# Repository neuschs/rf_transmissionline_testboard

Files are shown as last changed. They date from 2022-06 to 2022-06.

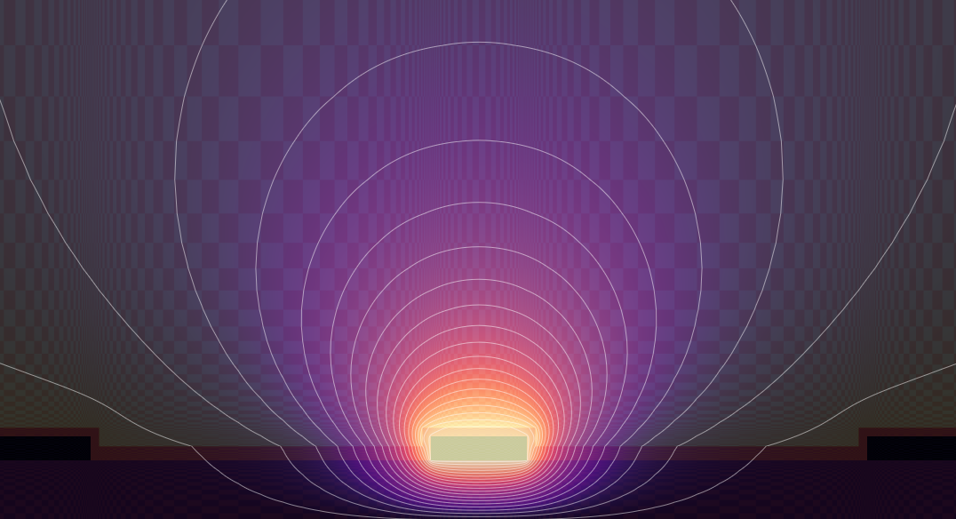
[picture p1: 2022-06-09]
calculations/coplanar_waveguide_single_e_field.png

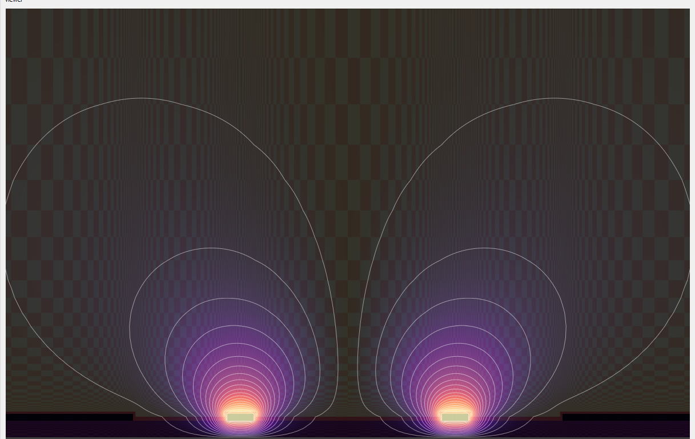
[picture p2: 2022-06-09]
calculations/coplanar_waveguide_differential_e_field.png

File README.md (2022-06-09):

# Transmission Line Testboard 
A simple PCB designed according to JLC23313 layer stackup 

There are many different impedance controlled transmission lines, with the most common Zo = 50 Ohm / Zdiff = 100 Ohm

- Coplanar Waveguide (Single / Differential)

- Microstrip (Single / Differential)

- Stripline (Single / Differential):

  A impedance controlled Via and a set of differential vias gets the stripline up to a coplanar waveguide to the sma connectors
  For a future version vertical SMA mounts would be better to avoid vias where the goal was to proof impedance control calculations.
 
- 90° track (as Coplanar Waveguide)

  I put this track on the pcb to measure the effects of 90° bends on transmission lines.

- 50% top 50% bottom track connected by 50 ohm via:
 to verify impedance of via if the coplanar waveguide calculations are all correct.

# Parameters @ production:

Base Material: FR-4\
Layers: 4\
Dimension: 100 mm* 100 mm\
PCB Qty: 5\
Product Type: Industrial/Consumer electronics\
Different Design: 1\
Delivery Fomat: Single PCB\
PCB Thickness: 1.6\
Impedance: yes JLC2313\
PCB Color: Green\
Silkscreen: White\
Surface Finish: HASL(with lead)\
Deburring/Edge rounding: No\
Outer Copper Weight: 1\
Inner Copper Weight: 0.5\
Gold Fingers: No\
Flying Probe Test: Fully Test\
Castellated Holes: no\
Remove Order Number: Yes\
Min hole size/diameter:0.2/0.45mm\
4-Wire Kelvin Test:No\
Material Type:FR4-Standard Tg 130-140C\
Paper between PCBs:No\
Appearance Quality:IPC Class 2 Standard\
Confirm Production file:Yes

# Credits
I mostly calculated the values with https://www.maartenbaert.be/alterpcb/tlinesim/ which has quite accurate interpretation of all different parts of the pcb.
After comparison, this tool was nearly exactly the same to the manufacturer (JLCPCB) regarding a 50 Ohm transmission line with JLC2313 stackup.

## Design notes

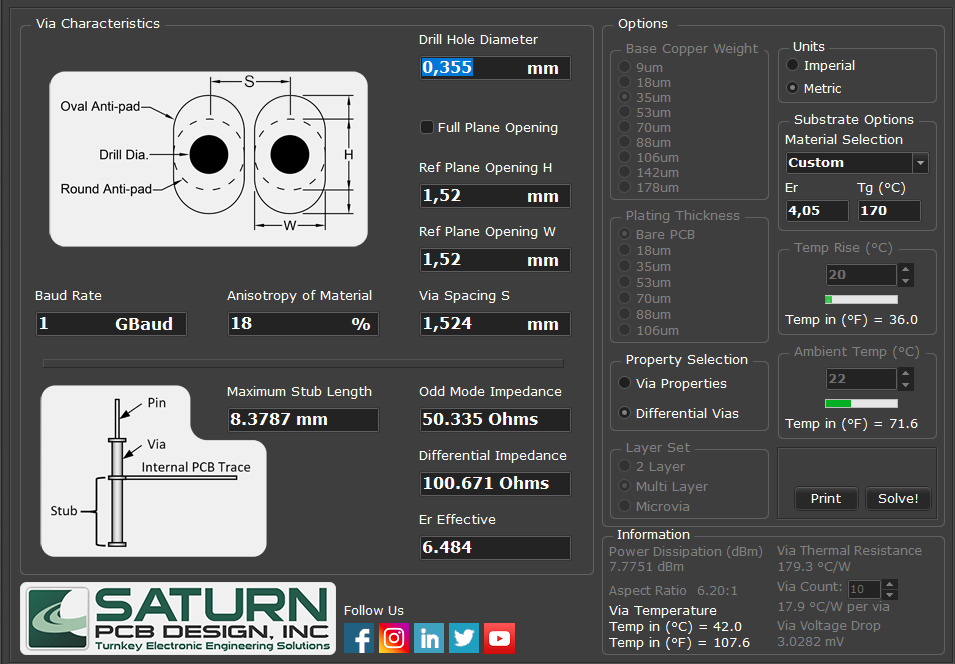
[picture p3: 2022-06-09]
calculations/differential via.png

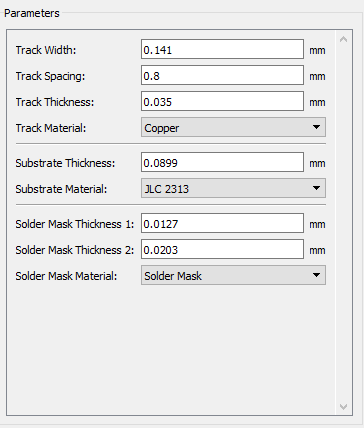
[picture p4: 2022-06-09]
calculations/microstrip_differential_parameters.png

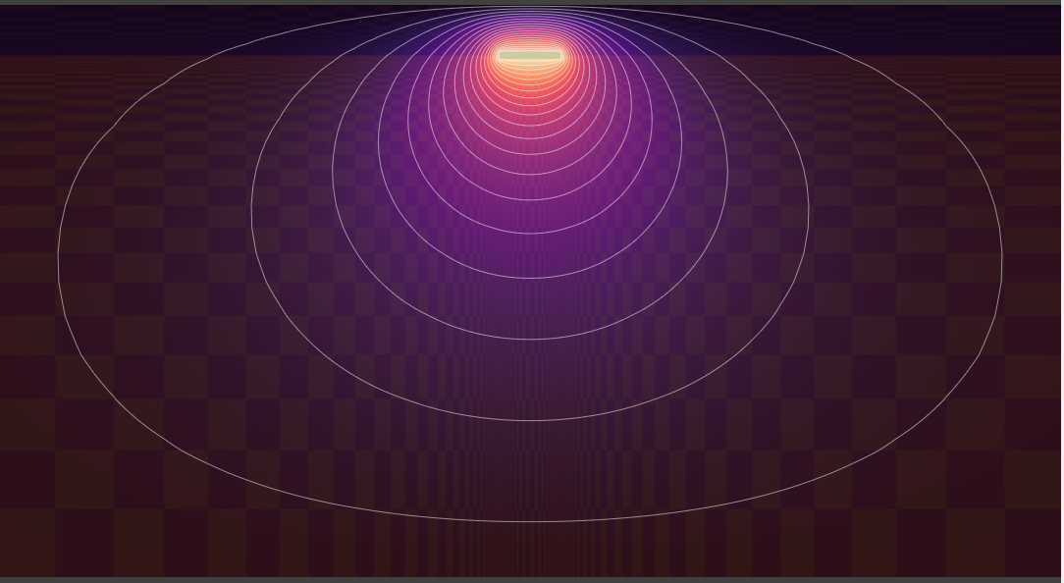
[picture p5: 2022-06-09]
calculations/stripline_single_e_field_layer_2.png

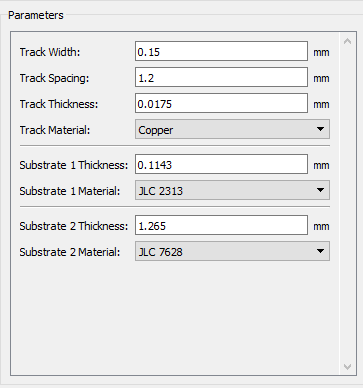
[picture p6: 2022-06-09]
calculations/stripline_differential_parameters.png

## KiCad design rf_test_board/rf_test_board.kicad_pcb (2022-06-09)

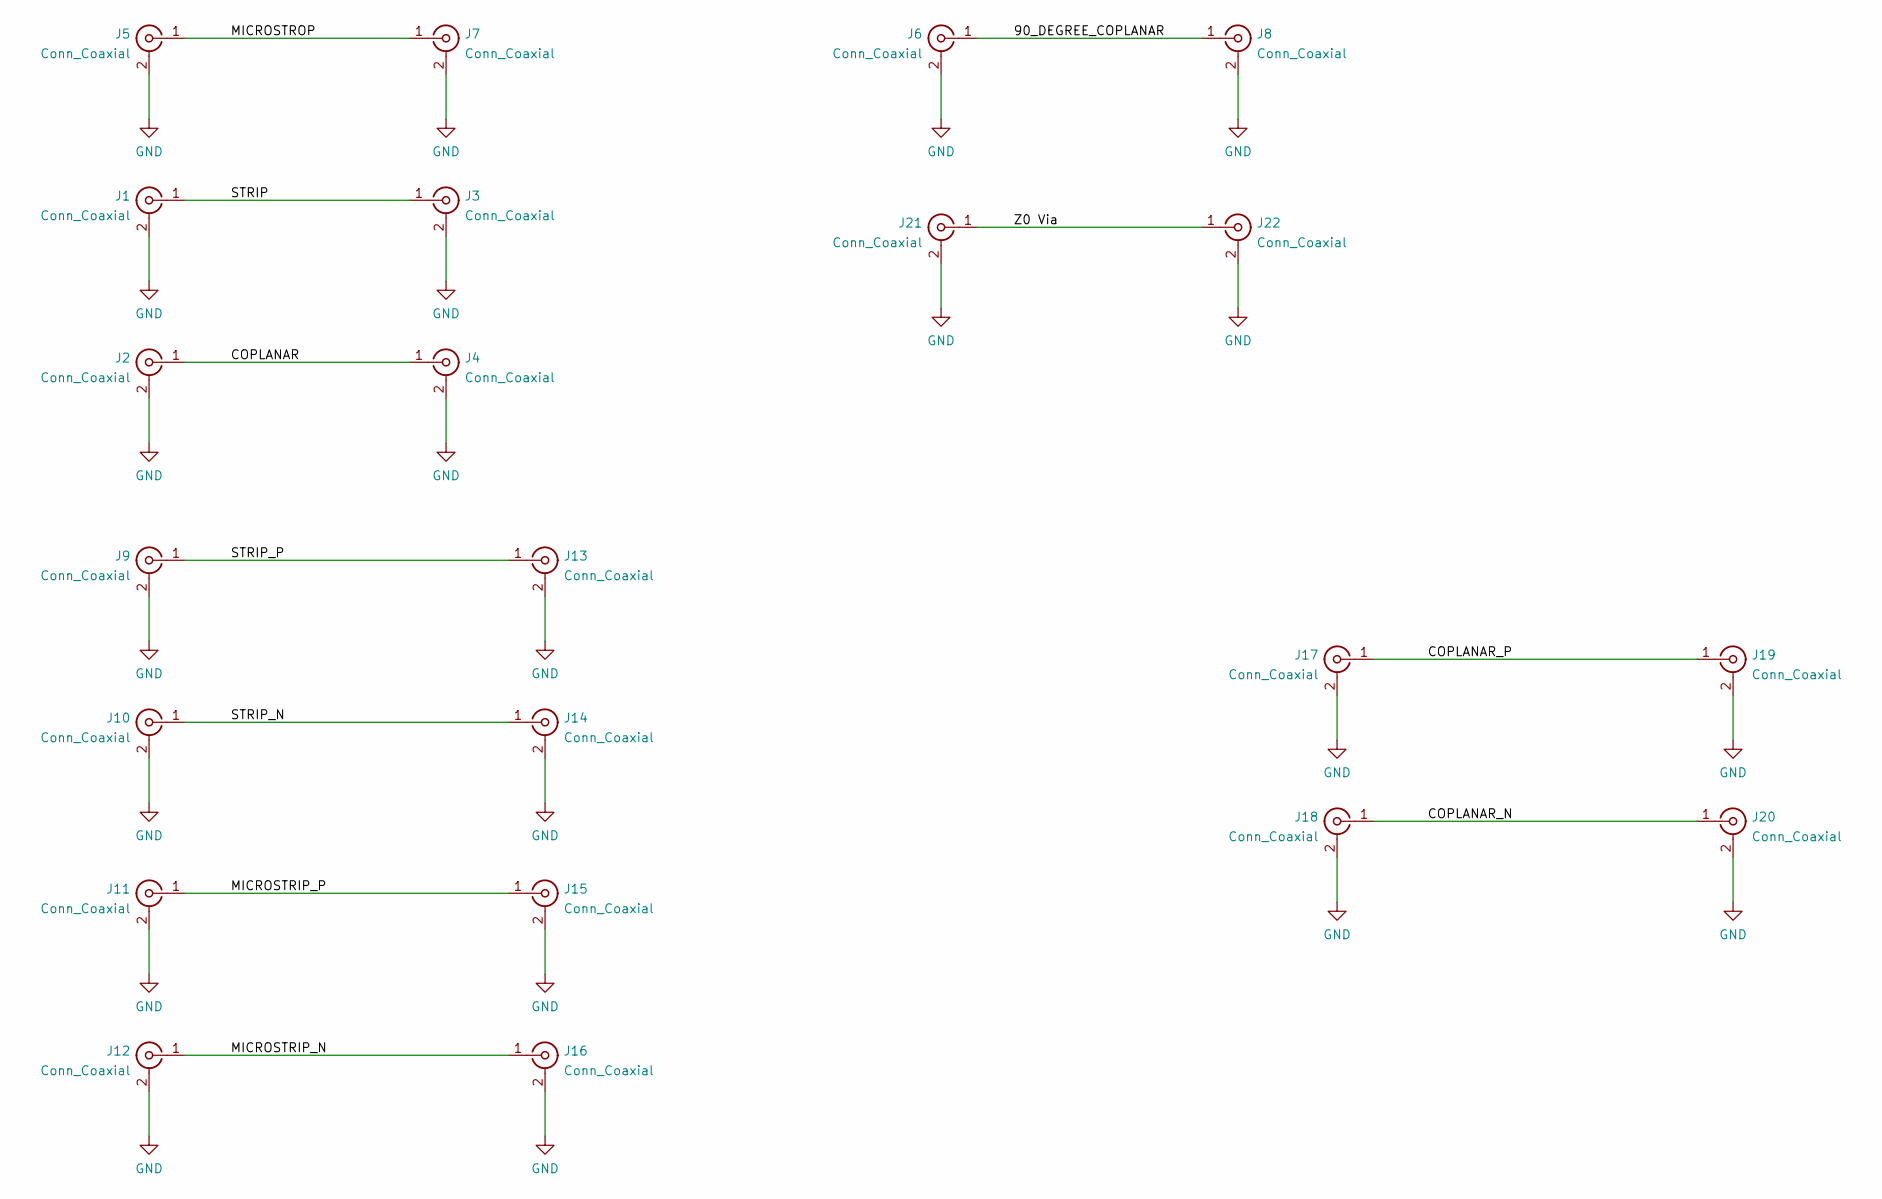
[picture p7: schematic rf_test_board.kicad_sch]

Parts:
J1, J2, J3, J4, J5, J6, J7, J8, J9, J10, J11, J12, J13, J14, J15, J16, J17, J18, J19, J20, J21, J22: Conn_Coaxial; SMA_Molex_73251-1153_EdgeMount_Horizontal

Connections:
/90_DEGREE_COPLANAR: J6.1 (In), J8.1 (In)
/COPLANAR: J2.1 (In), J4.1 (In)
/COPLANAR_N: J18.1 (In), J20.1 (In)
/COPLANAR_P: J17.1 (In), J19.1 (In)
/MICROSTRIP_N: J12.1 (In), J16.1 (In)
/MICROSTRIP_P: J11.1 (In), J15.1 (In)
/MICROSTROP: J5.1 (In), J7.1 (In)
/STRIP: J1.1 (In), J3.1 (In)
/STRIP_N: J10.1 (In), J14.1 (In)
/STRIP_P: J9.1 (In), J13.1 (In)
/Z0 Via: J21.1 (In), J22.1 (In)
GND: J1.2 (Ext), J2.2 (Ext), J3.2 (Ext), J4.2 (Ext), J5.2 (Ext), J6.2 (Ext), J7.2 (Ext), J8.2 (Ext), J9.2 (Ext), J10.2 (Ext), J11.2 (Ext), J12.2 (Ext), J13.2 (Ext), J14.2 (Ext), J15.2 (Ext), J16.2 (Ext), J17.2 (Ext), J18.2 (Ext), J19.2 (Ext), J20.2 (Ext), J21.2 (Ext), J22.2 (Ext)

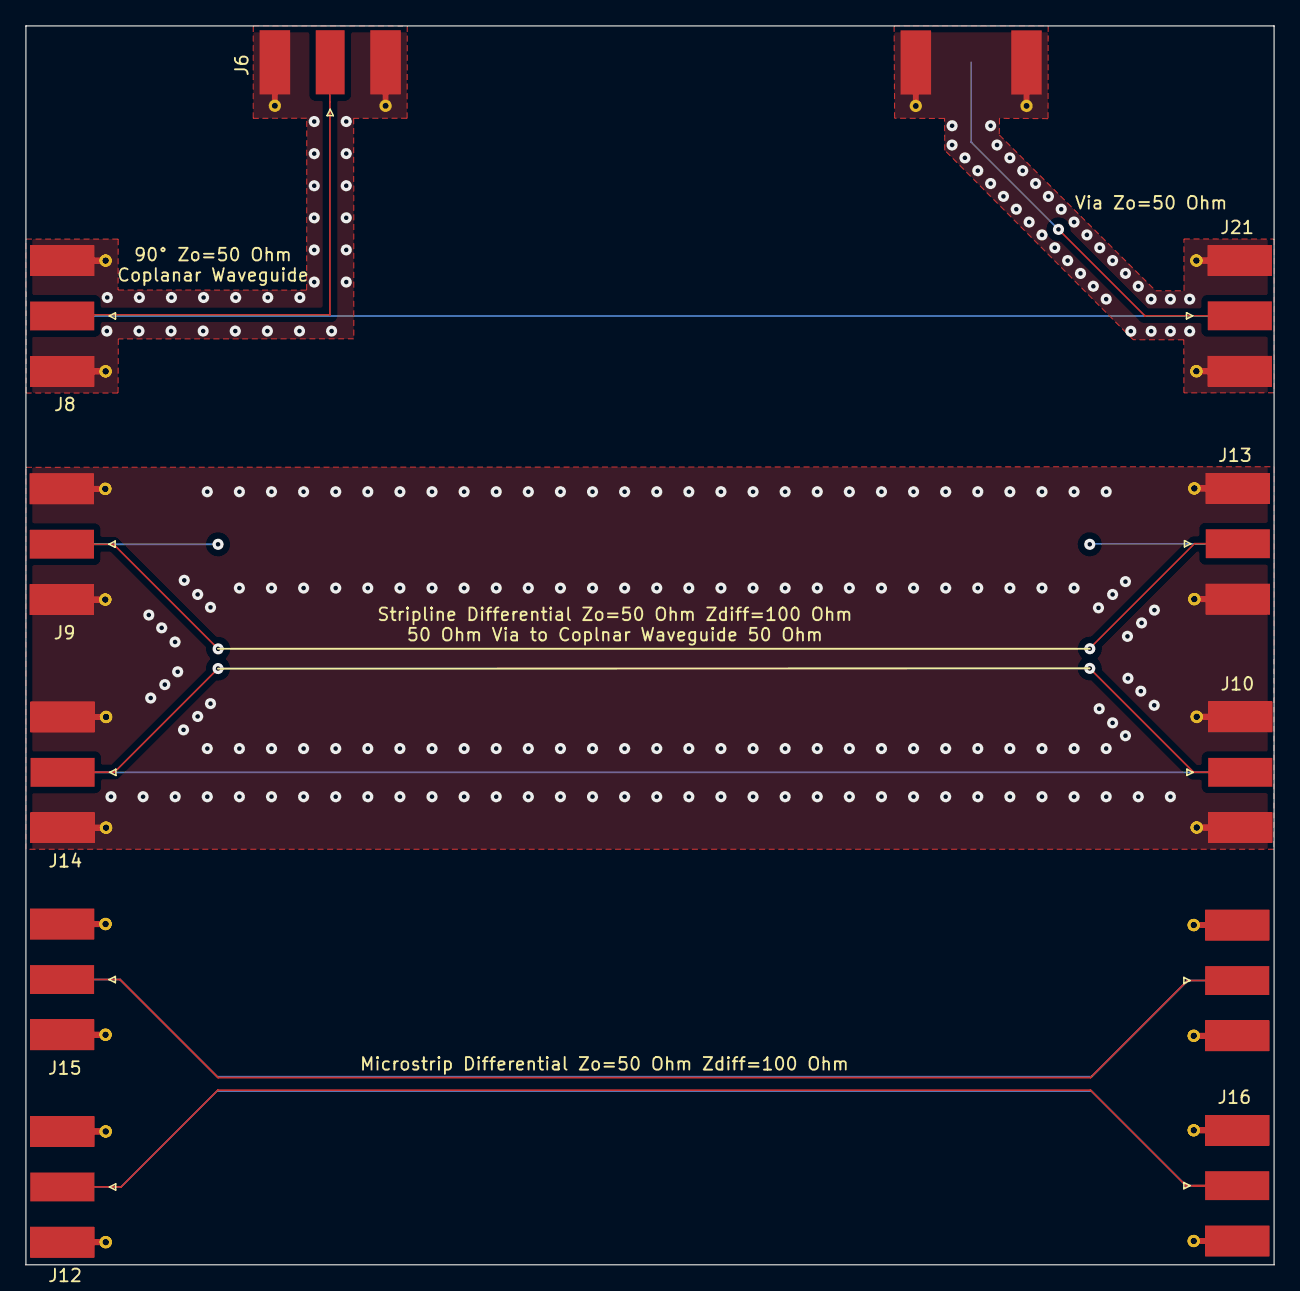
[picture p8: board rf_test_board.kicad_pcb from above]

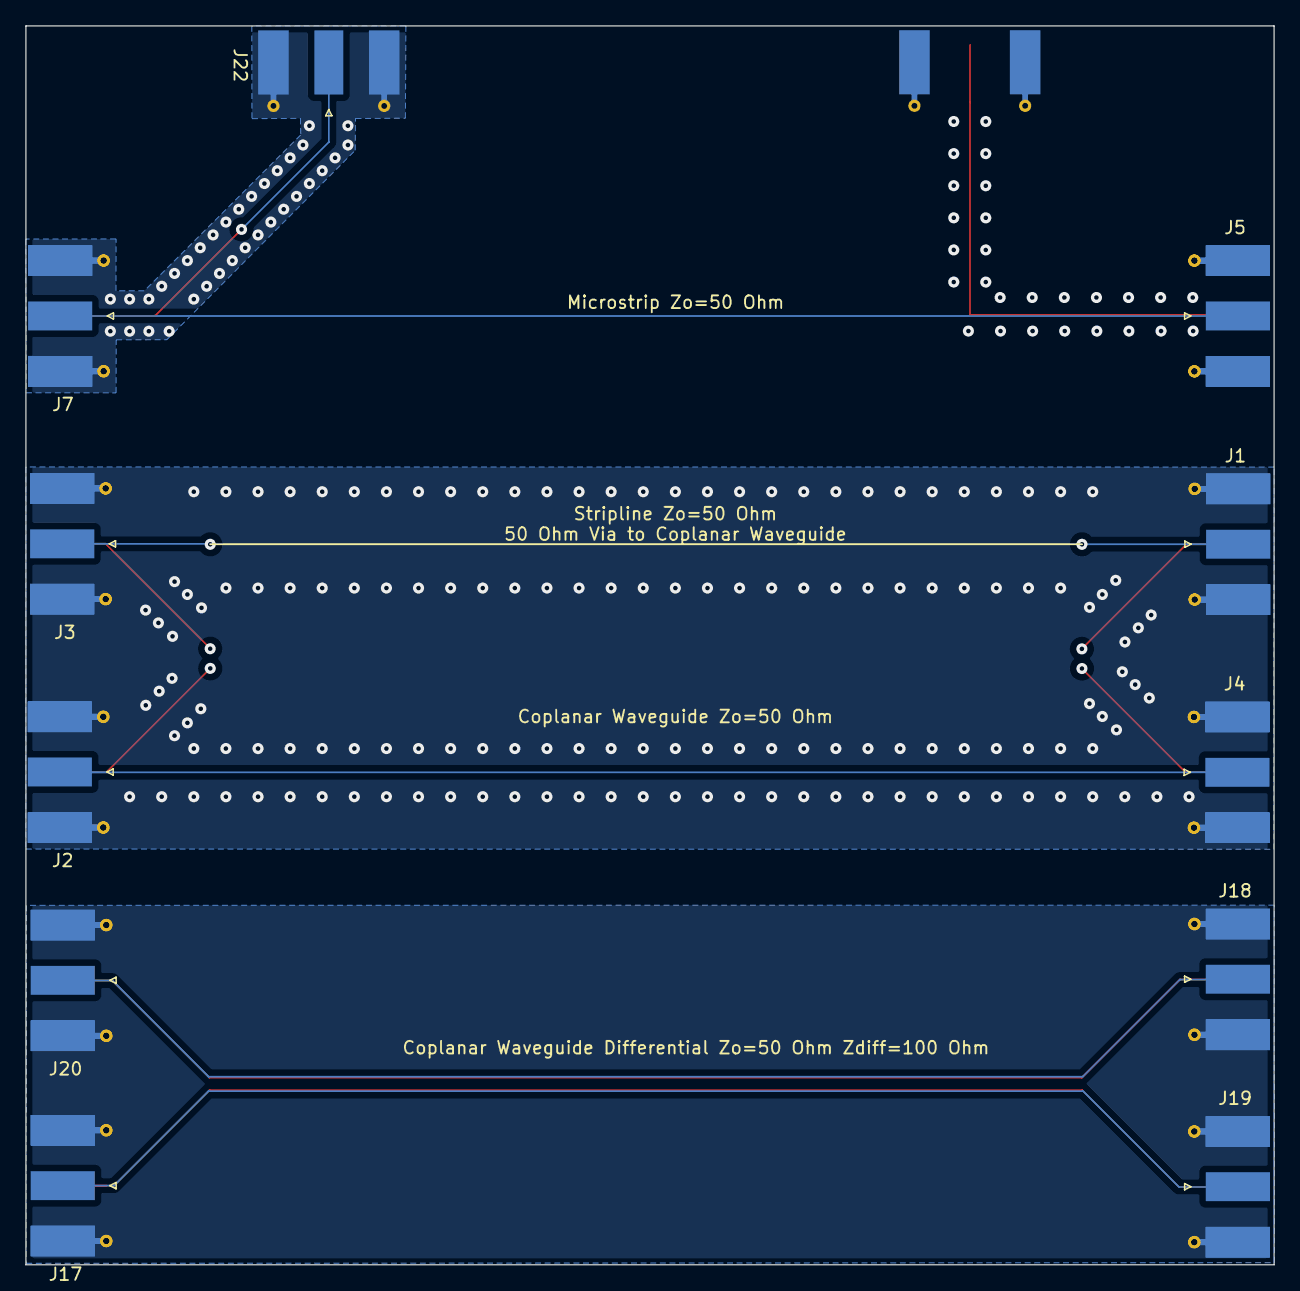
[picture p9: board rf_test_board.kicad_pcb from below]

Board: 4 copper layers, 98.8 x 98.0 mm, 22 parts (11 on the bottom side), 12 nets.
